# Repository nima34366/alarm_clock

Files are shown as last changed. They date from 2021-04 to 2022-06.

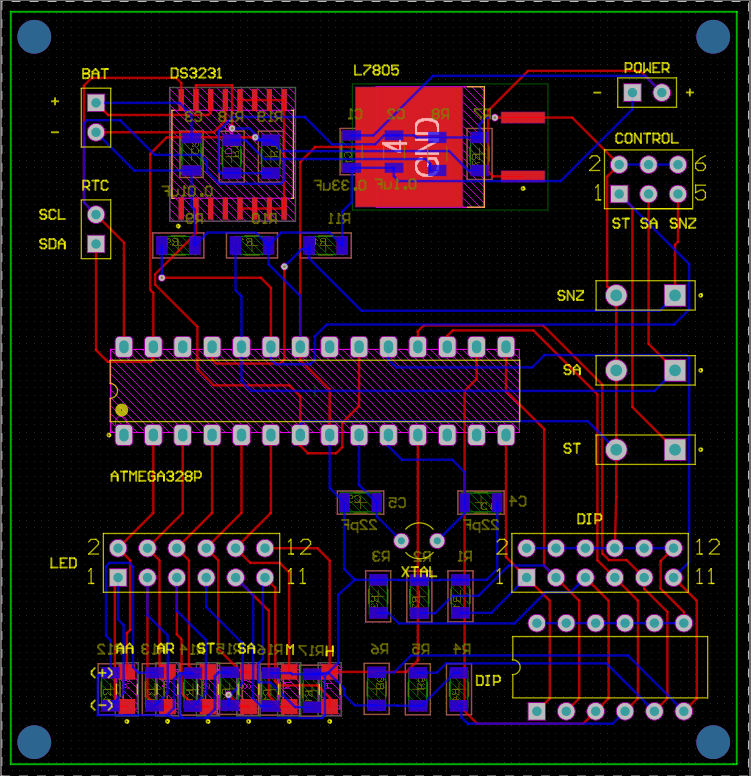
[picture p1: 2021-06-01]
microproducts/alarm_timing/pcb_design/PCB Layout.png

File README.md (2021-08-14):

# alarm_clock
This repository was created by Group 28 [Batch 19] for the Lab project (Alarm Clock) done in Semester 2 in University of Moratuwa.

It contains,
- The code required to function the Alarm clock along with code that is required to interface it with the ATMEGA644P, 16x2 LCD Screen, 4x3 Matrix Keypad and Buzzer.
- Pdfs of the schematics and layout used to create the PCB and the final renderings of Enclosure cerated using Solidworks.
- The latex files used to create the Final Report.

Link to the Google Drive that contains Altium and Solidworks files used to create the PCB and Enclosure: https://drive.google.com/drive/folders/1GlEg0UCcHJv6p5PrgpzKblIw5QNwTWeP?usp=sharing

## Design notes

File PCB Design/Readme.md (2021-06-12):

# Documentation of the PCB Design for the final Alarm Clock

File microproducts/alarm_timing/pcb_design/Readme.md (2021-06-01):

# PCB Design
This folder contains the documentation of the PCB design.\
The complete Altium project folder can be viewed from the following link.\
https://drive.google.com/drive/folders/1xslyNMAareKGrAWDZLLcO-WtdoEgDhnP?usp=sharing \

The PCB has the DS3231 RTC IC integrated onto it and is controlled by ATmega328P microcontroller.\
LEDs and switches have been used as indicators and controllers. These LEDs and switches have been placed on the PCB board but separate sets of headers have been added to draw wires when they need to be installed on an enclosure.\
SMD LEDs, resistors and capacitors have been used to decrease the area size of the PCB.\
The manufactured and assembled PCB's photographs are included in the drive link along with a demo.\

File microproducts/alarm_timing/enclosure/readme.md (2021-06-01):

# Enclosure Design
This Folder contains the design files of the Enclosure.\
All the Solidworks files can be accessed through the following link.\
https://drive.google.com/drive/folders/11zQsuTPlsv7nsFcpykirxAldbuCoP8ur?usp=sharing

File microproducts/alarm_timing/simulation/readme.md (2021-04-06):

# Files of Proteus simulation

The stage 1 implementation on the breadboard is demonstrated in the following video.
https://drive.google.com/file/d/18iBrARlaOofpYiVowA4YhBBXxcqHcPaR/view?usp=sharing

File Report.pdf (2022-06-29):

# Alarm Clock EN1093 - Semester 2 Project

Wickramasinghe N.L. 190688X∗

, Widanagamage T.R. 190691B†
,
Widanapathiranage D.N. 190692E‡

, Wijegunawardana C.H.W. 190696U§ Department of Electronic and Telecommunication Engineering University of Moratuwa, Sri Lanka Email: ∗wickramasinghenl.19, †widanagamagetr.19, ‡widanapathiranagedn.19, §wijegunawardanachw.19@uom.lk

Abstract—Our objective was to design and implement an alarm
clock that includes set time, date, and alarms throughout the day with the features of delete, change, and selecting an alarm tone. Initially, the complete code was implemented using Arduino C++. We transferred it into AVR C++ at the latter part of the project. For testing purposes, Proteus software was used. In parallel to the code, schematics and PCB layout were developed while having an idea of the conceptual design. The enclosure design was developed using Solidworks, including all the features needed to set the alarm for the user. Further, the physical product was developed to get final results, correcting all the impairments beforehand using proteus simulation. Throughout this project, we gained programming skills, improved logical thinking, PCB design skills, enclosure designing skills, and improved teamwork skills.
I. INTRODUCTION
In this paper, we have discussed the development of a digital alarm clock. Our objective was to create an alarm clock with the functions of,
- Set current date and time
- Set an alarm with the features of change, delete, and selecting a tone
- Factory reset
We navigated through various challenges to identify and experience the whole process of developing a product from scratch to the final complete product.
The significant parts of the alarm clock are keypad input, LCD, alarm timing, and audio output. Complete firmware for the parts was developed separately and combined to develop the final firmware using AVR C++. The ATMEGA644P microcontroller was used to develop this product.
In this paper, we have included the methods of the development of,
- Firmware
– Algorithms for each of the subsystems key input, menu display, alarm timing, and audio output
– Final Algorithm
- PCB Design
– Components used
– Schematic Diagrams
– PCB layout
- Enclosure Design
The objective of our project was to create a digital alarm clock that had a smooth user interface while having all the functions required in an alarm clock. We also worked on creating an accurate PCB that required very little space and, finally, creating a sleek and modern enclosure design for the product.

II. METHOD

A. Firmware Development

The task was to come up with an algorithm to implement an alarm clock with the following functions. The user should be able to add multiple alarms and add favorable tones to each of those alarms.
1) Set current time
2) List the existing alarms
3) Change or delete an alarm
4) Set a new alarm
5) Select an alarm tone
6) Factory reset
The system was planned to be implemented on AT-Mega328p microcontroller which has 32kB memory. But the memory was found to be insufficient for the developed algorithm mainly due the memory taken up to store multiple tones for alarms and other arrays. Therefore, the microcontroller was upgraded to an ATMega644p which has 64kB of memory and has a DIP package. The firmware was developed for this microcontroller using Microchip Studio. The algorithms were tested in several initial stages on Proteus simulation software. During the prototype development, the code was uploaded to the microcontroller using USBasp open-source programmer via the AVRDude interface.
A keypad was used to take number inputs from the user and an LCD was used to display the user interface of the clock. A sound system comprised of a buzzer was used to generate sounds for the alarms. The alarm clock keeps track of time and date using the RTC IC DS3231 which communicates with the microcontroller through the I2C interface.
The firmware development was initially divided into 4 main sub-systems in which each member developed a library of functions to perform a unique set of tasks. Based on these firmware libraries, four independent micro-products were developed to demonstrate each of the set of functions that will later be combined to create the final product. The sub-systems and each of their functions are in Table I.

Sub-system | Functions
Key Input | Read number input from a 4x3 keypad Detect button pressings
Menu Display | Display messages generated by the microcontroller on the 16x2 LCD
Alarm Timing | Set time and date Set/Delete alarms Detect alarms
Audio Output | Select multiple tones Drive a buzzer to ring a tone
| Table I
SUB-SYSTEMS AND FUNCTIONS.

The microproducts were implemented in two stages. The team members developed the algorithms to implement each function and tested the algorithm using codes written in Arduino C++. These codes were tested on Arduino Uno boards using Proteus software. After satisfactory results the firmware was developed in AVR C++ for the ATMega microcontroller. All the tasks were written modularized into functions and all the inter-related functions were combined into header files(.h and .cpp files). The microproduct implementation was done using these header files.
Algorithms
1) Key Input: This sub-system provides two main functions from Table I. The keypad read function will wait for a keyinput from the user when the function is called. Once the user presses a key in the keypad, the function returns the pressed key as an integer. Figure 1 shows the algorithm of that function.

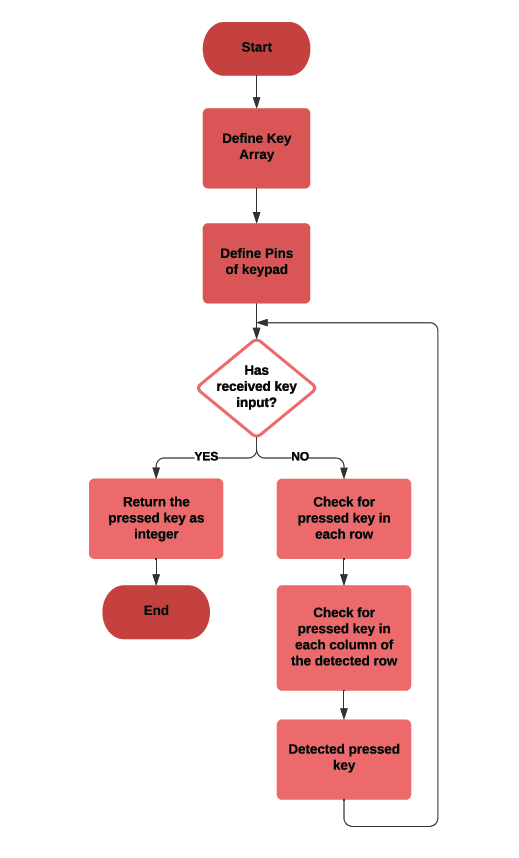
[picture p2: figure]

Figure 1. Keypad Read Algorithm

The button press function checks if a switch has been pressed and return True if yes, False if not.The algorithm is illustrated in Figure 2.

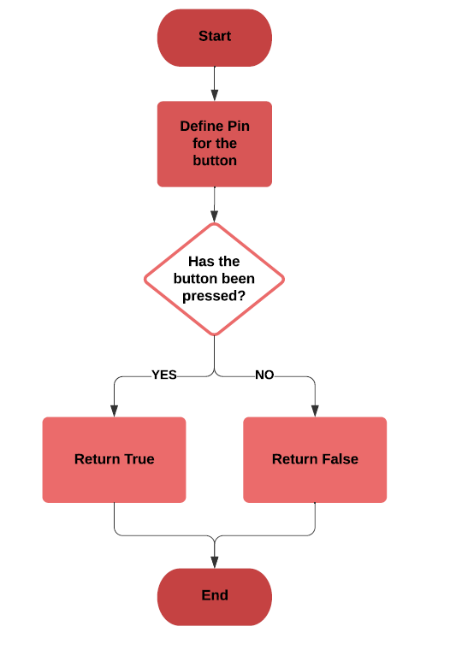
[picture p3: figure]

Figure 2. Button Press Algorithm

2) Menu Display: Two types of functions were written for controlling and displaying messages on the LCD.
- Control Functions
- Display Functions
The Table 2 and Table 3 shows the control functions and display functions respectively.
Function Name | Task Performed
LCD_Command(cmd) | Sending unique commands to setup the LCD
LCD_Char(char) | Sending unique characters to setup the LCD
LCD_Init() | Initial setting up of the LCD
LCD_String(string) | Sending a string to LCD
LCD_String_xy(row,col,string) | Sending a string to LCD with (x,y) position
LCD_Clear() | Clear LCD
Table II
DISPLAY FUNCTIONS OF LCD
3) Alarm Timing: The firmware for this sub-system was written based on objected oriented programming. Three classes were created with their own variables and methods. The classes are
- Time
- DS3231
- Alarm
a) Class Time: This class consists of the following set of variables that define the Time/Date. A single constructor method exists to create an instance of class Time.
- Hour
- Minute
- Second
- Year
- Month
- Day

Function | Snapshot

Home

Menu

Invalid Input

Set Time Menu

Alarm List

Alarm Menu

Select Tone

Setting Digits

Confirm Time/Date/Alarm

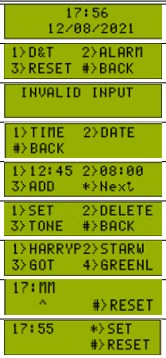
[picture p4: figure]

Table III
DISPLAY FUNCTIONS OF LCD
b) Class DS3231: This sub-system interacts with the RTC DS3231 IC to maintain the timekeeping. As aforementioned, the microcontroller communicates with this IC through I2C communication. This class contains the variables and methods required for that purpose and the functions for setting/reading time and date to/from the registers of the RTC IC. The necessary registers of the IC were referred from it’s datasheet. [1] The following necessary set of functions that interface the I2C communication[2] and encoding/decoding functions were written. They are provided in Table 4.
Function Name | Task Performed
begin | Initialize pins and bit rate and enable TWI
burst_read | Send address to start reading and read from that address
write_register | Send address to write value and write to that address
decode | Convert hex representation to integer value
encode | Convert integer value to hex representation
Table IV
I2C FUNCTIONS

Then these functions in Table 5 were used to write the following functions to be used in the timekeeping.

Function Name | Task Performed
set_Time | Write time to necessary registers in the IC
set_Date | Write date to necessary registers in the IC
get_Time | Read Time/date from registers and return the time as an object of Time
get_TimeStr | Return a string of time
get_DateStr | Return a string of date
Table V
TIMEKEEPING FUNCTIONS

Using the above three classes, five central functions were written to perform the following tasks.

Function Name | Task Performed
Timing_set_time | Read input from keypad and set time
Timing_set_date | Read input from keypad and set date
Timing_set_alarm | Read input from keypad and set an alarm
Timing_delete_alarms | Delete all alarms
Reset_time | Factory reset
Table VI
ALARM TIMING FUNCTIONS

The algorithm that was being used to set time/date/alarm is given in Figure 3.

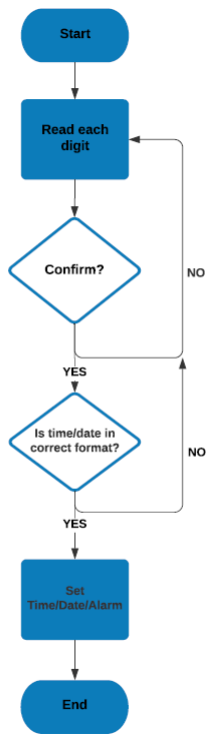
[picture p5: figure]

Figure 3. Set Time/Date/Alarm Algorithm

4) Audio Output: All the notes with the durations were taken from a github repo [3].They were modified to create two seperate header files. One header file “notes.h” defined the frequencies of each note of music used in the tones. The second header file “tones.h” defined two arrays with the notes and their respective durations for each of four tones as follows.
- Harry Potter
- Star Wars
- Game of Thrones
- Green de Leaves
A class Tone was created with the following variables and two functions.
- Array of note

- Array of durations
- Length
- Rate
The following functions in Table 7 were implemented to perform the respective tasks.
Function Name | Task Performed
Play_note | Play the note for the respective duration on the buzzer
Audio_play | Play the tone until the user stops the alarm
Table VII
AUDIO OUTPUT FUNCTIONS

The following Figure 4 and Figure 5 show the algorithms for play_note and audio_play functions.

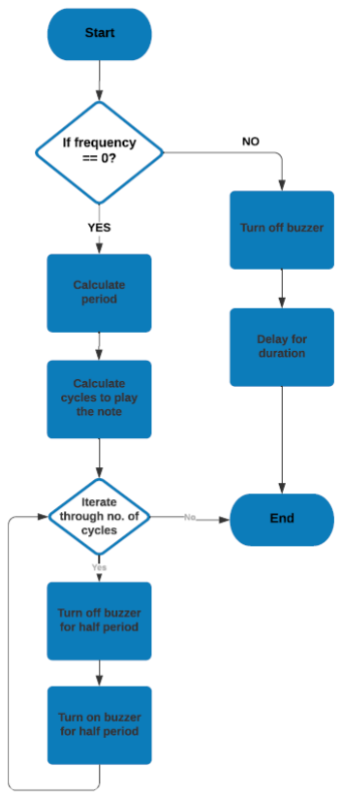
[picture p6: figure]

Figure 4. Play Note Algorithm

Final Product
The algorithm of the final product implemented a user interface of a menu system for the alarm clock according to the following algorithm in Figure 6. It makes use of functions of the above explained header files.
The checks for alarm times were implemented using software interrupts. The reason for using interrupts was to detect alarms even when the user is in the middle of the menu. The Timer Overflow Interrupt of 16-bit Timer/Counter 1 of ATMega644p was used in this case. The interrupt service routine (ISR) was written to iterate through each alarm in the

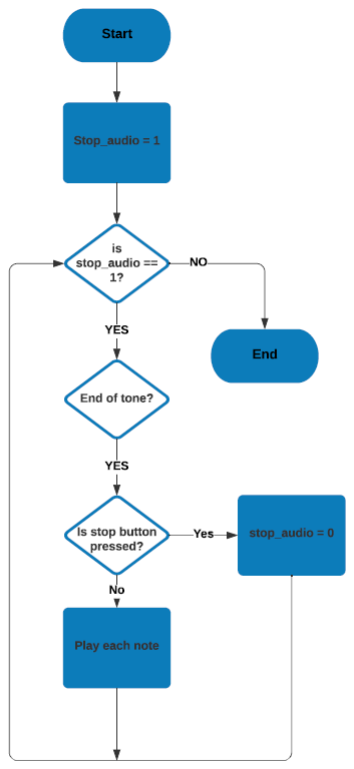
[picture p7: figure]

Figure 5. Audio Play Algorithm

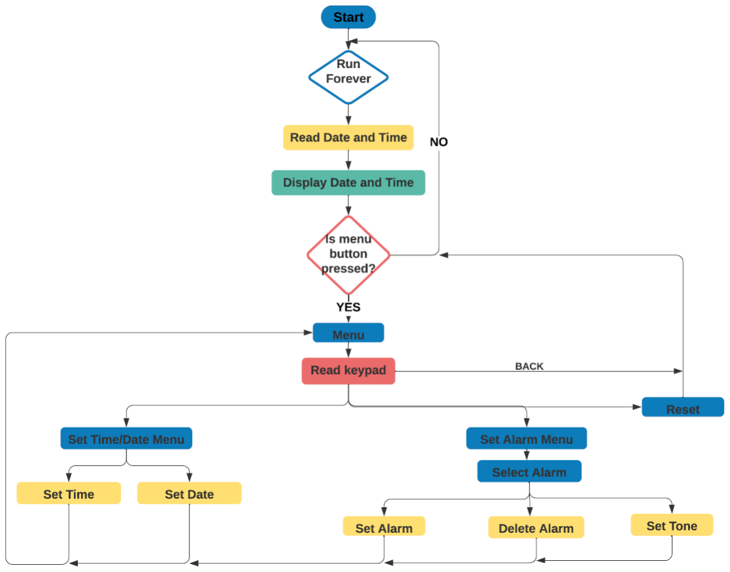
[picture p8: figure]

Figure 6. Main Algorithm

alarm list and check whether the time is equal to any of the active alarms. If found, its ring function will be called. Between the menu, an error message was programmed to be displayed whenever the user entered an invalid input. The AVR C++ codes of the firmware of the alarm clock can be found at the GitHub link in the appendix.

B. PCB Design
1) List of components used:
a) Microcontroller: According to the Atmega644p microcontroller datasheet, 0.1 uF bypass capacitor was provided to connect VCC and GND. [4]
- Atmega644P microcontroller
- 0.1 uF capacitor
- Reset switch
- 10k resistor
b) Power regulator: LM7805 has been selected as the regulator and according to the datasheet the two capacitor values were chosen. [5]
- 2 pin header for the power supply.
- LM7805
- 0.33 uF capacitor
- 0.1 uF capacitor
c) Programmer:
- 10 pin header for the USBASP
d) Buttons:
- 2 pin header *2 for the menu button and stop button.
- 10k resistor
e) Keypad:
- 7 pin connector for the keypad
- 10k resistor*4
f) LCD display:
- 12 pin connector for the lcd display
- 1k resistor
g) RTC clock: According to the DS3231 datasheet values of the resistors have been decided. [1]
- DS3231 IC
- 10k resistors*2
- 2 pin header for the coin cell battery
h) Buzzer:
- 1N4001 diode
- BC547 transistor
- 220 resistor
- 2 pin header for the buzzer
i) Oscillator:
- 16 MHz crystal oscillator
- 22 µF capacitor*2
Reasoning for use of particular components Microcontroller: Atmega644P microcontroller was chosen for the project due to several reasons. First, the program was implemented using 328P microcontroller and the memory of that was not enough. Atmega328P has 32 Kbyte flash memory, 1 Kbyte EEPROM and 2 Kbyte RAM. Then the microcontroller was upgraded to Atmega644P [Figure 7, Figure 8] because it has 64 Kbyte flash memory, 2 Kbyte EEPROM, 4 Kbyte RAM and 40 pins. [4]
Keypad: 4*3 keypad was chosen instead of 4*4 keypad because only ‘*’ button and ’]’ button were taken other than the number buttons for the control of going back and set functions.

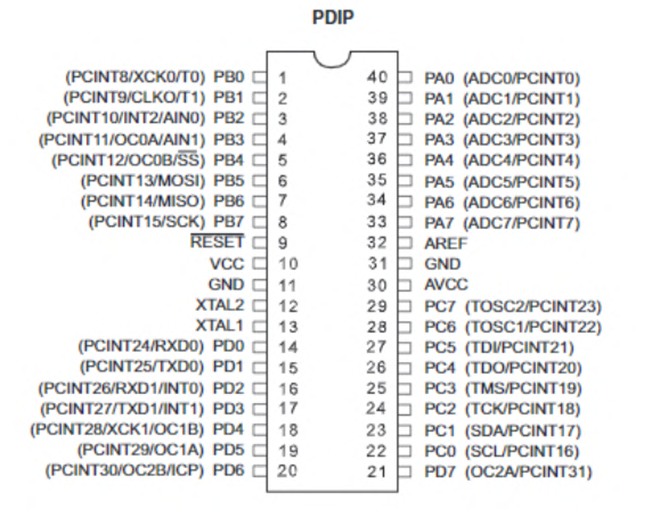
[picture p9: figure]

Figure 7. Pinout644P

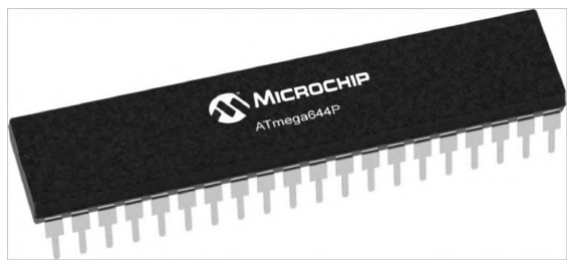
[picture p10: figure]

Figure 8. Atmega644P

Switches: The purpose was to minimize the number of switches in the enclosure for the convenience of the user. Even through a button of the keypad can be taken for the menu button, a separate switch is provided because the user will be used menu button several times and if there’s a separate switch user can recognize it easily as menu button other than providing a keypad number as the menu button. There is another switch for stop alarm because if it is given as a keypad button, user gets difficult to off while awake in sleep. Therefore, a separate button is provided for the stop alarm, then user can easily switch off.
Real Time Clock(RTC) IC: After comparing DS1307 and DS3231, DS3231 module was selected. DS3231 IC is more accurate than DS1307 IC but it is existing only as a SMD component. DS3231 has been chosen because it’s not an issue for soldering. [1]
Buzzer circuit: A transistor has been used for the amplifying purpose and a diode has been used to make the protection for the buzzer.
Batteries: There are two batteries, 1.5V, 4AAA batteries are used as main voltage supply and a silver coin cell battery is used as a backup battery for the RTC module. Even though there are two batteries, the user doesn’t always have to replace the coin cell battery, because the coin cell battery provides current to the RTC module only if there isn’t a main voltage supply. The required current for the DS3231 IC module is given in the datasheet as 200 uA. The capacity of a silver coin cell battery is 200 mAh. If coin cell battery provides 20 hours of current per month, the user can use one coin cell battery for about 4 years without replacing it. The required voltage for the circuits is 5V. Then it should supply 5v or more than that. The batteries available in the market are AA and AAA batteries. Therefore four 1.5v batteries must be provided. The size of the AA batteries is quite larger than AAA batteries therefore the enclosure battery holder has to be enlarged. As a result, 4 AAA batteries were selected.
2) PCB layout: The Schematic diagram and the PCB Layout made for the design of PCB can be found in Figure 19 and Figure 20 respectively.
Considerations in PCB design
- The board size, neatness and the shortest routing path were generally considered.
- The placement of bypass capacitor(C3) near to the micro controller according to the data sheet.
- Minimized routing traces through the oscillator and placed near to the micro controller.
- Capacitors of the oscillator, placed near to it (C4, C5).
- The same value of resistors placed in line for the convenience of soldering purpose.
- All header connectors were placed close to edges of the board because of the convenience of connecting wires.
- Capacitors of the regulator, placed near to it. (C1, C2) The dimensions of the final PCB were 61.6 mm x 45.3 mm. The top and bottom of the 2D and 3D views can be found in Figures 21, 22 and Figures 23, 24 respectively.
C. Enclosure design
Designing the enclosure is one of most important parts in the process of product development. A product enclosure should have the characteristics of
- Strength – To withstand the stresses during normal use
- Functionality – Have the necessary components for proper functionality of the product
- Attractive – A sleek, aesthetic, and modern design to attract potential buyers
- Easy to handle – The product should be able to be operated by anyone without prior experience about the particular product
The goal of our team was to create a suitable enclosure for the housing of the electronics of our digital alarm clock. Our aim was to create an enclosure that would have the necessary strength for day to day use. It should also have the requirements to be easily opened for repairs and maintenance while having a very unique and aesthetic design.
Our enclosure had to be able to house the following components within the enclosure.[Figure 9]
- 2 x Momentary switch
- 1 x Printed circuit board along with the electronics
- 1 x Coin cell battery holder
- 1 x 4xAAA Battery holder
- 1 x Buzzer
- 1 x 4x3 Matrix keypad
- 1 x LCD screen display
- Necessary Wires
(a) PCB | (b) Keypad
(c) 4xAAA Battery Pack | (d) Momentary Switch
(e) Coin cell battery holder | (f) Buzzer
(g) LCD

Figure 9. Components to be placed within the Enclosure

Figure 10 shows the initial sketches we had planned for the enclosure design of the digital alarm clock.

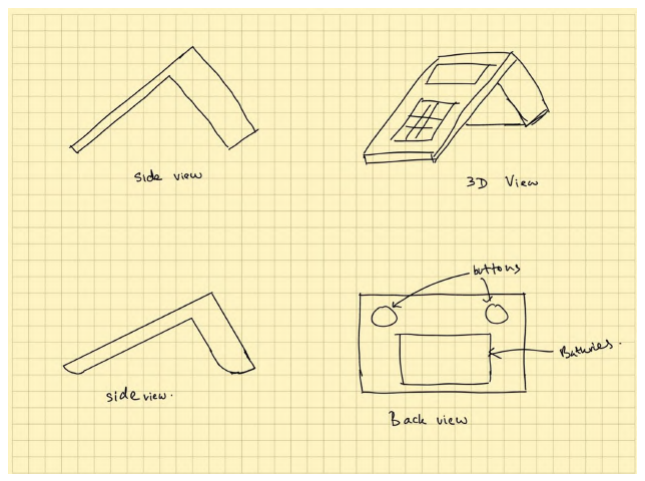
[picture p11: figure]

Figure 10. Initial sketches

Our Final enclosure is split into 3 separate parts.

- Bottom part
- Top part
- Battery cover

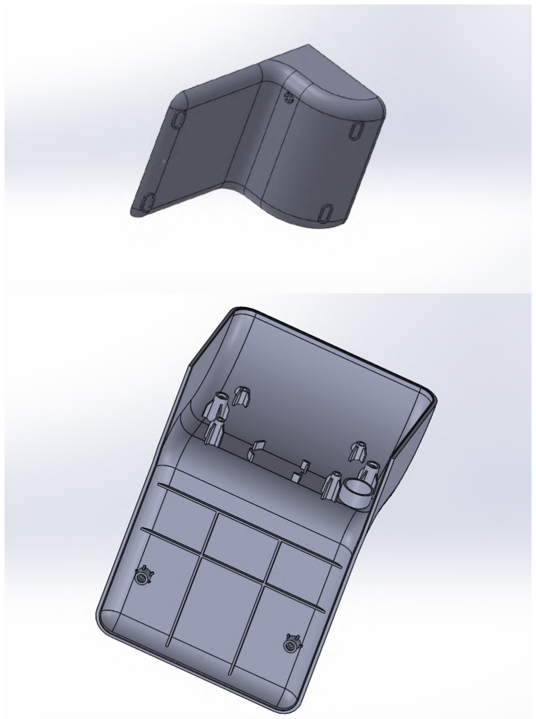
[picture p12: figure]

Figure 11. Bottom part

1) Bottom part [Figure 11]: The bottom part gets connected to the top part using four mounting bosses. Also, lips and grooves are etched onto the edges where the two parts meet. It also contains ribs for additional support and high strength. It also helps to maintain shape under high-stress conditions. The bottom part houses the coin cell battery, PCB, and the buzzer. We created a separate slot to accommodate the coin cell battery. The PCB is mounted on 4 mounting bosses. A circular slot is separately carved to accommodate the buzzer. A vent is created on the bottom side to pass the sound of the buzzer outside. 4 straight slots are etched onto the bottom surface, where rubber pads will be attached later on. The rubber pads on the bottom will help stabilize the product and help stop slipping.
2) Top part [Figure 12]: The top part too includes the required mounting bosses to connect to the bottom part along with the lips and grooves. It houses the 4x3 matrix keypad, LCD, 4xAAA battery holder, and the two momentary switches. Separate holes are cut out for the momentary switches to be attached. The holes have a carving above them so that the user can easily identify the function of the switch. A 1mm depth slot is carved out in the front face to accommodate the 4x3 matrix keypad. A small slot is cut at the bottom to get the wires inside the enclosure. A large window is cut at the top part of the front face for the LCD screen. Also a large slot is created at the back to accommodate the 4XAAA battery

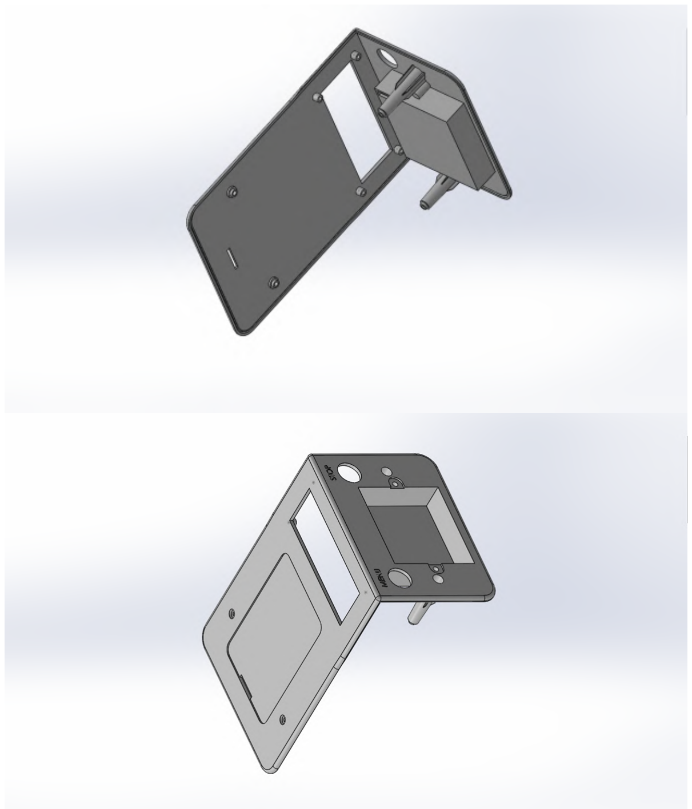
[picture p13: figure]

Figure 12. Top part

holder. It also contains the holes required to attach the cover of the battery compartment.

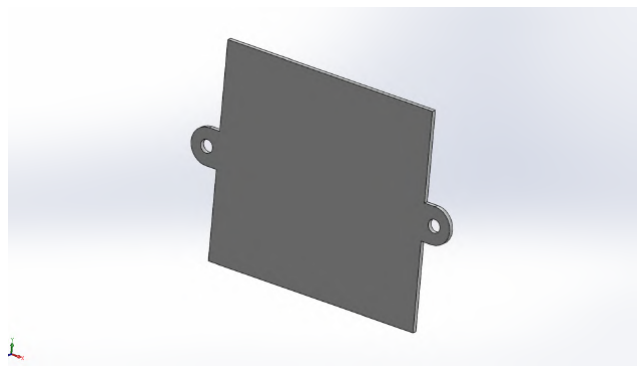
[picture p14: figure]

Figure 13. Battery cover

3) Battery cover [Figure 13]: A separate cover is created in order to cover the 4xAAA battery holder. The cover is fastened on to the top part using two screws.
The bottom part was colored with blue and the top with white for the final product. We used SolidWorks software for the creation of the 3D models. [Figure 14]

III. RESULTS

The alarm clock design was tested using the schematic in [Figure 15] using Proteus simulation software. The design was tested for setting time and date, setting multiple alarms, deleting alarms, detecting the alarms, stopping the alarm and resetting functions. All four tones were tested successfully.

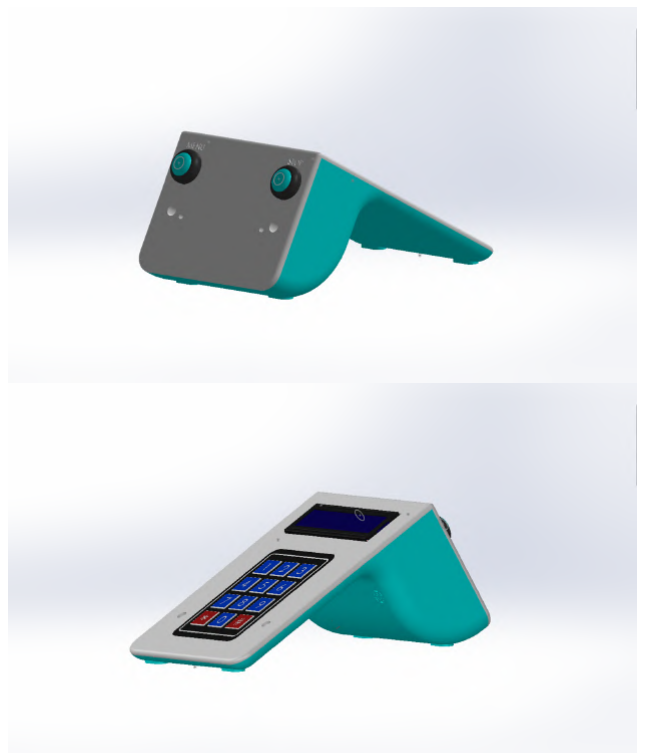
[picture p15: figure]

Figure 14. Final Enclosure

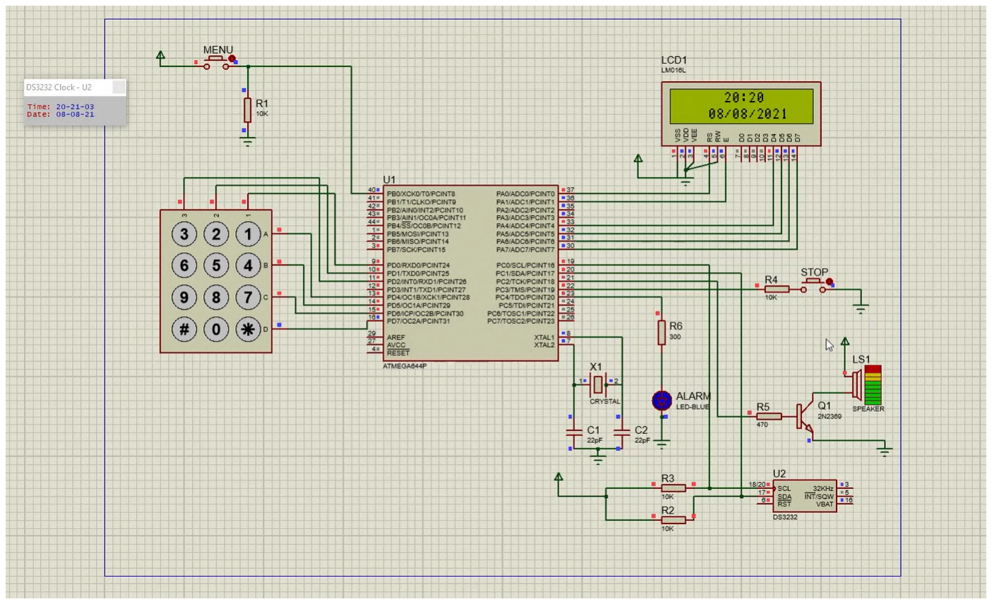
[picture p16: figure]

Figure 15. Proteus Simulation

A recording of the Proteus Simulation could be found by following the Google Drive link in the appendix. After the algorithm and the schematic were confirmed using Proteus, the circuit was implemented on breadboard to be evaluated on real-life aspects. The circuit performed as expected giving similar results as in Proteus simulation. [Figure 16] shows the breadboard testing.

Then the PCB was manufactured from JLCPCB from China and the components were purchased from Arrow Electronics. [Figure 17] [Figure 25] [Figure 26] The components were hand soldered to the PCB and tested using a prototype in [Figure 18]

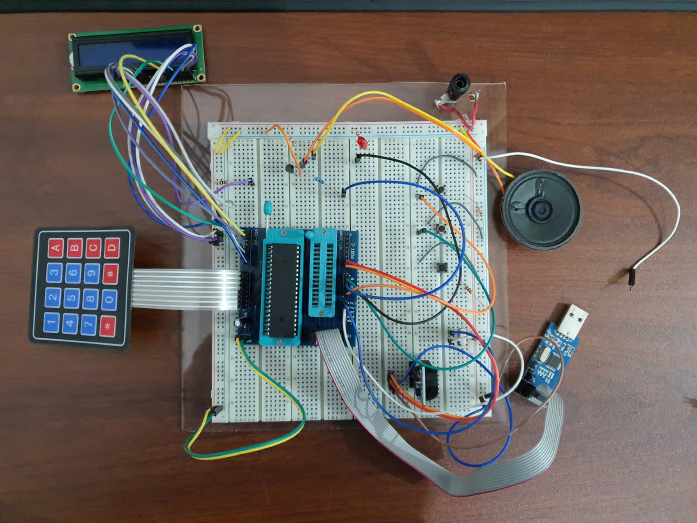
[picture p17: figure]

Figure 16. Breadboard Testing

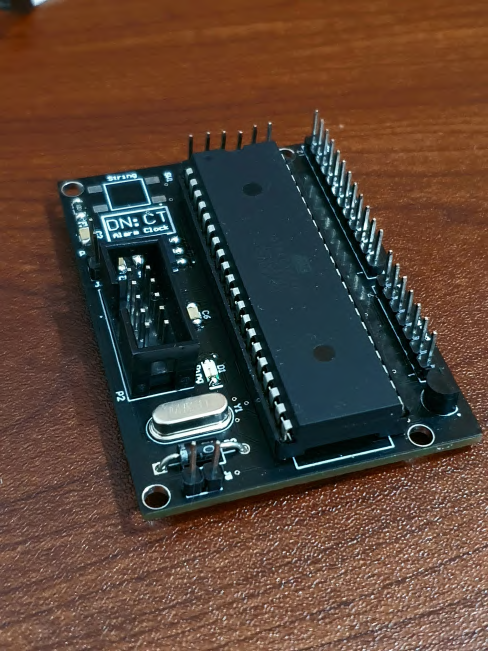
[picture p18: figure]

Figure 17. The Fabricated PCB

IV. DISCUSSION
There were several challenges we faced during the project of designing the alarm clock. During the development of the firmware, it was required to combine modularized code written by several people into a single project. To make it easier, a flowchart was drawn for the central algorithm and the functions were modified into a common code writing style. The codes were well documented to be understood by other collaborators. After making the circuit on the breadboard, the Port C of the micro-controller happened to be not working properly, supposedly due to the continuous I2C communication through the same port. The components on Port C were shifted to unoccupied pins in Port B. However, this error did not occur in the Proteus simulation which emphasized the

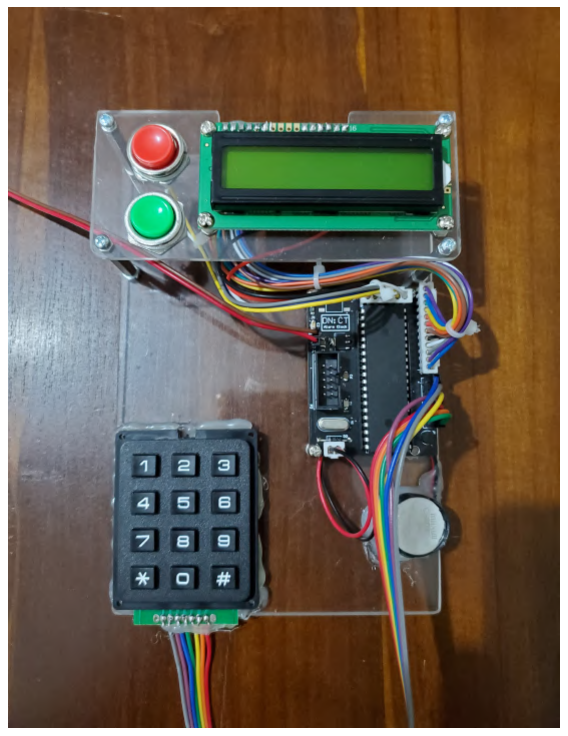
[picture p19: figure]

Figure 18. Prototype

importance of testing the circuit in physical conditions. Compacting components to get a smaller PCB was a challenge when designing our PCB. Specially, the upgraded micro-controller Atmega644P is considerably larger than the previous Atmega328P which in turn increased the form factor. The final dimensions of the PCB were 61.6 mm x 45.3 mm, which is satisfactory. The PCB was manufactured by JLCPCB. Therefore, it was required to adhere to the rules given by JLCPCB. The pads around the pins of the transistor in its footprint were too close to each other, violating clearance rules. To solve this, the size of the pins of the transistor were taken from it’s data sheet and the footprint was adjusted. When placing the components, the components which are taller in height like headers were placed only on one side of the PCB to avoid being required to keep space on both sides of the PCB when it is being mounted in the enclosure. Also, even though the coin cell battery can be inserted on the PCB itself, it was placed in the enclosure because the purpose was to make PCB smaller in size.
Software, such as SolidWorks, helped us to easily design unique and functional enclosures for our electronic products. Most of the 3D models for the components we used could be found online, which was very helpful when deciding the required dimensions for the enclosure. Although we planned to 3D print and assemble our final product, we were unable to do it due to not being able to gather the some of the components within the given time frame. But, the the error analysis method given by the SolidWorks software itself showed no errors with the final enclosure [Figure 14].
There are several improvements that could be made to the design of this alarm clock. The LCD could be connected to the micro-controller using an I2C multiplexer, which will reduce the number of pins required. Also, in our current design, 4 AAA batteries were used to supply 5V power to the electronic components. But this makes the alarm clock bulky and inconvenient for the user who will have to replace 4 batteries when they drain out. Instead, a boost converter could be integrated into the circuit to draw power from a single AAA battery. However, this was not implemented in the current stage of development, because it was not in our knowledge scope yet.
V. CONCLUSION
Design of the alarm clock for our semester 2 project for the module EN1093 helped us in gaining many technical skills as engineers. Developing firmware for an electronic product using ATMega micro-controllers, designing a schematic and a PCB layout for an electronic circuit using Altium, fabricating and soldering a PCB, designing a commercially viable enclosure for an electronic product using Solidworks and testing an electronic product for design verification were the most valuable skills we gained during the project. We adhered to the important stages of the product development life cycle and gained social skills of working as a team to achieve a common goal. Our design of the alarm clock performed all the functions of the project requirements, contained an easily comprehensible user interface using an LCD and a keypad, and possessed a stable and attractive enclosure.

ACKNOWLEDGMENT
We would like to express our sincere gratitude to our supervisors Mr. Kithmin Wickramasinghe, Mr. Abarajithan Gnaneswaran and Mr. Pasan Dissanayaka, for their enthusiasm, insightful comments, helpful information, and practical advice. All of them helped tremendously during the completion of this project. The project would not have been possible to complete without the support and guidance from the supervisors. We thank our parents for the financial support given to us in completing this project.

REFERENCES

[1] Maxim Integrated, “Ds3231 datasheet,” https://pdf1.alldatasheet.com/datasheet-pdf/view/336170/MAXIM/DS3231.html, (https://pdf1.alldatasheet.com/datasheet-pdf/view/336170/MAXIM/DS3231.html) accessed 15-07-2021.
[2] California State University, Long Beach, “Serial communications and i2c,” http://web.csulb.edu/~hill/ee346/Lectures/20%20C++%20ATmega%20I2C%20Serial%20Comm.pdf/, (http://web.csulb.edu/~hill/ee346/Lectures/20%20C++%20ATmega%20I2C%20Serial%20Comm.pdf/) accessed 15-07-2021.
[3] R. | Couto, | “arduino-songs,” | https://github.com/robsoncouto/
arduino-songs, (https://github.com/robsoncouto/arduino-songs) 2021.
[4] Microchip Studio, “Atmega644pa datasheet,” https://pdf1.alldatasheet.com/datasheet-pdf/view/313648/ATMEL/ATmega644PA.html, (https://pdf1.alldatasheet.com/datasheet-pdf/view/313648/ATMEL/ATmega644PA.html) accessed 15-07-2021.
[5] Texas Instruments, “Lm7805 datasheet,” https://pdf1.alldatasheet.com/datasheet-pdf/view/838007/TI1/LM7805.html, (https://pdf1.alldatasheet.com/datasheet-pdf/view/838007/TI1/LM7805.html) accessed 15-07-2021.

VI. APPENDIX
Link to GitHub Repository: https://github.com/nima34366/alarm_clock
The following Google Drive link contains the following documents related to the project: https://drive.google.com/drive/folders/1GlEg0UCcHJv6p5PrgpzKblIw5QNwTWeP?usp=sharing (https://drive.google.com/drive/folders/1GlEg0UCcHJv6p5PrgpzKblIw5QNwTWeP?usp=sharing)
- Microchip Project File
- Altium Project File
- Solidworks File
- Bill of Material
- Proteus Simulation
- Prototype Simulation

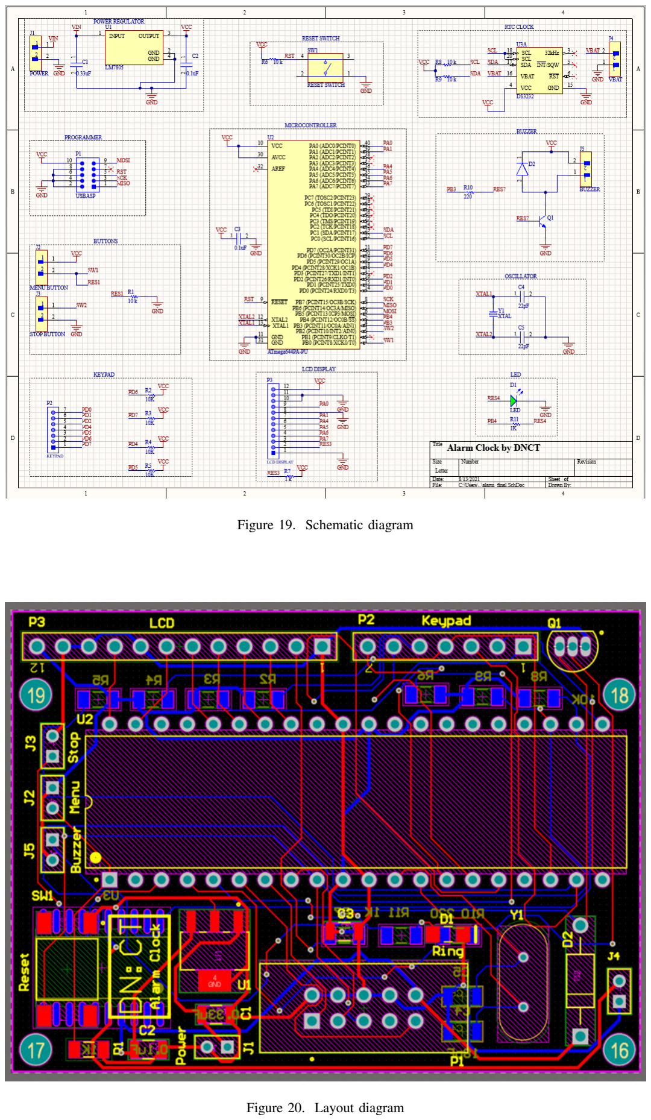
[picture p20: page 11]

Figure 19. Schematic diagram

Figure 20. Layout diagram

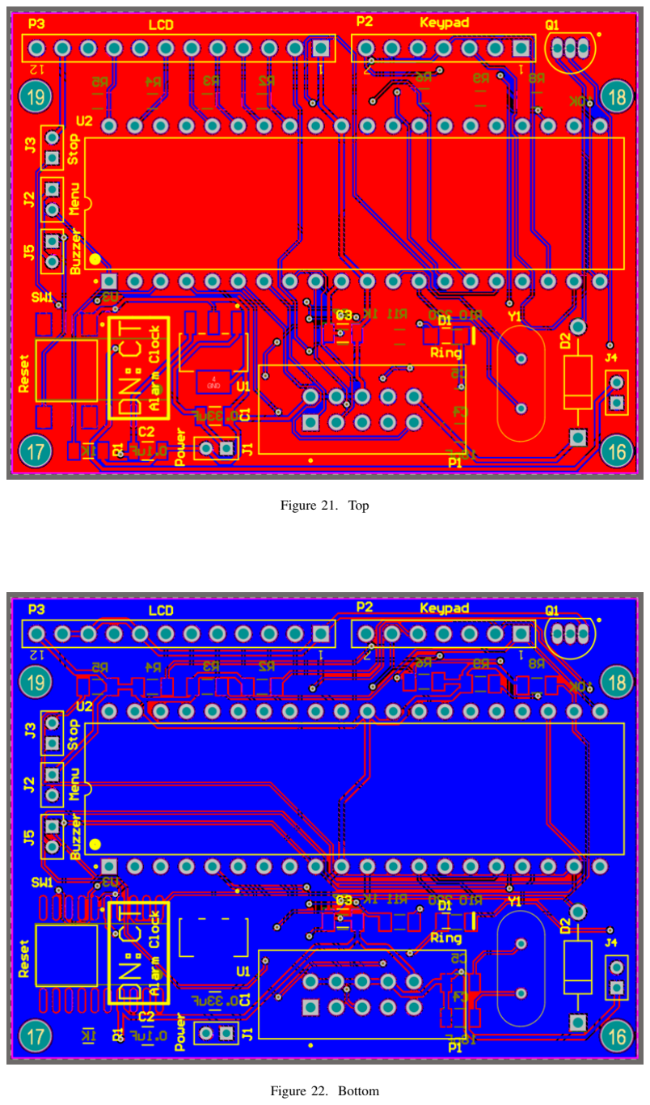
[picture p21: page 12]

Figure 21. Top

Figure 22. Bottom

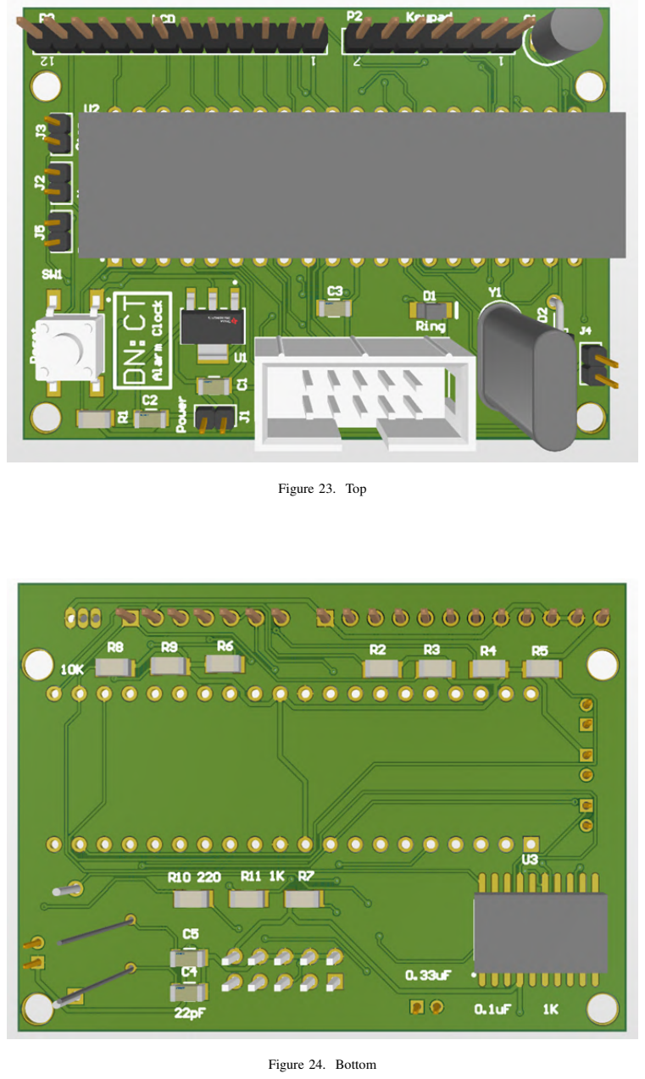
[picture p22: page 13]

Figure 23. Top

Figure 24. Bottom

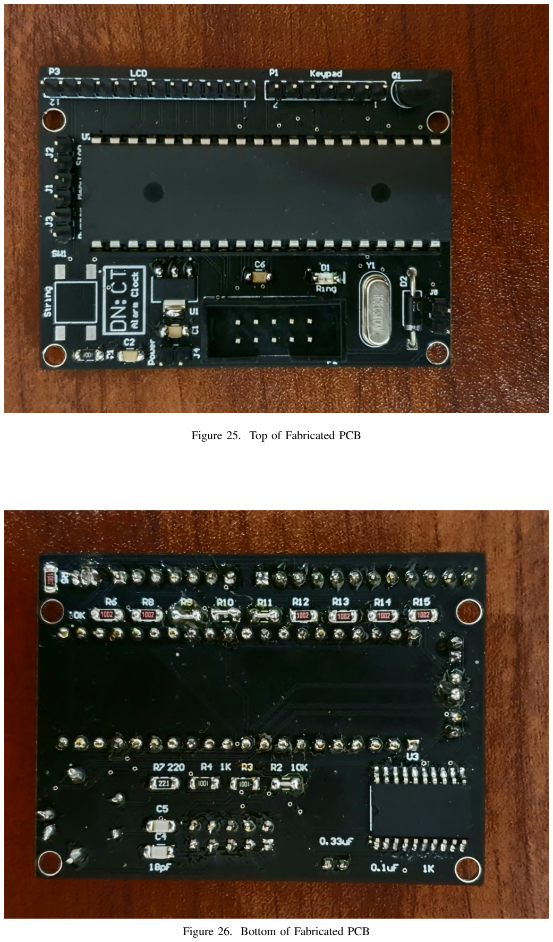
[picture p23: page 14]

Figure 25. Top of Fabricated PCB

Figure 26. Bottom of Fabricated PCB

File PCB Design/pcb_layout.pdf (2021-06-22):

PCB Layout

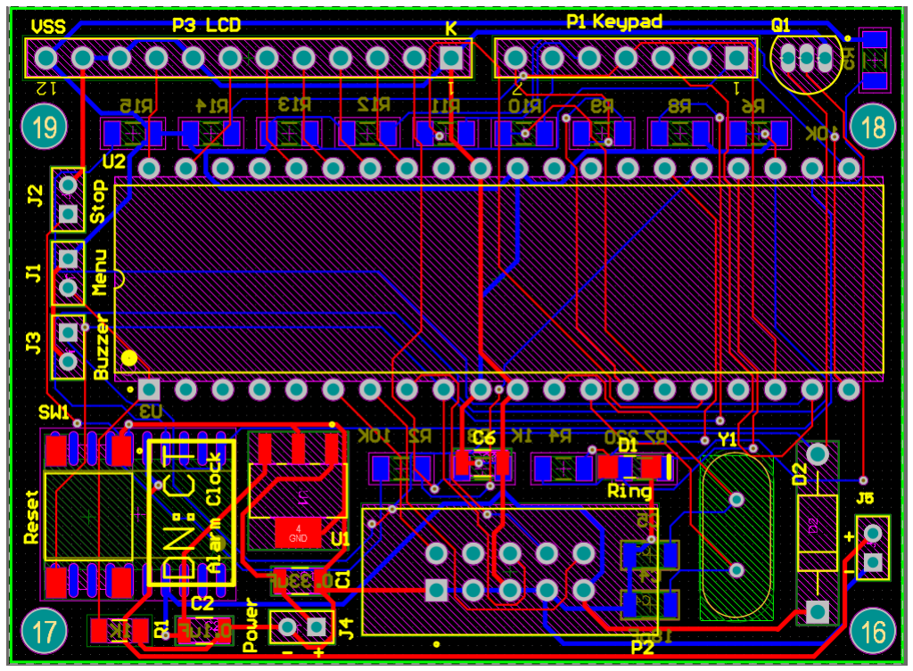
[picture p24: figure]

Routing

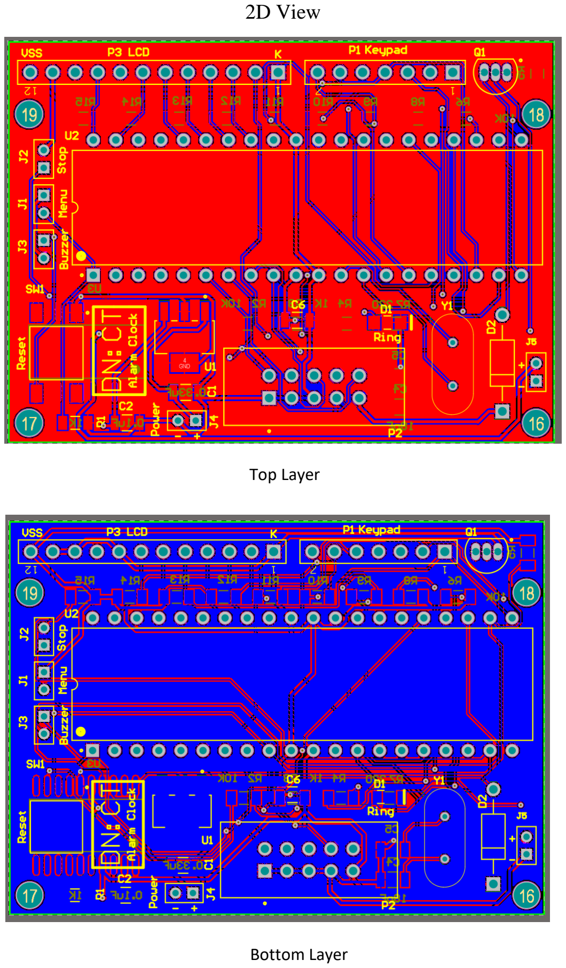
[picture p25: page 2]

2D View

Top Layer

Bottom Layer


3D View

Top View

Bottom View


Side View

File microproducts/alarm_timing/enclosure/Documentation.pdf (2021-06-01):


3D View

Top View


Front View

Left View


Cross View

Bottom View

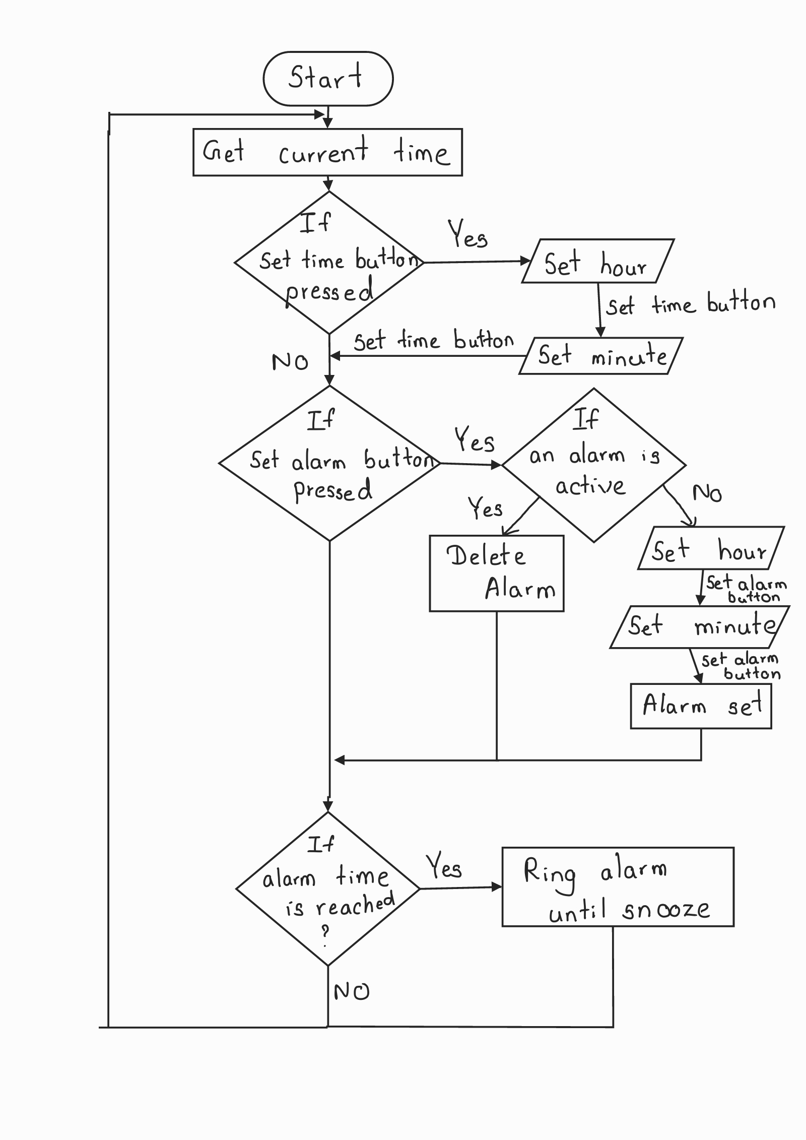
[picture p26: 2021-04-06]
microproducts/alarm_timing/simulation/Block Diagram of Alarm Timing.jpg

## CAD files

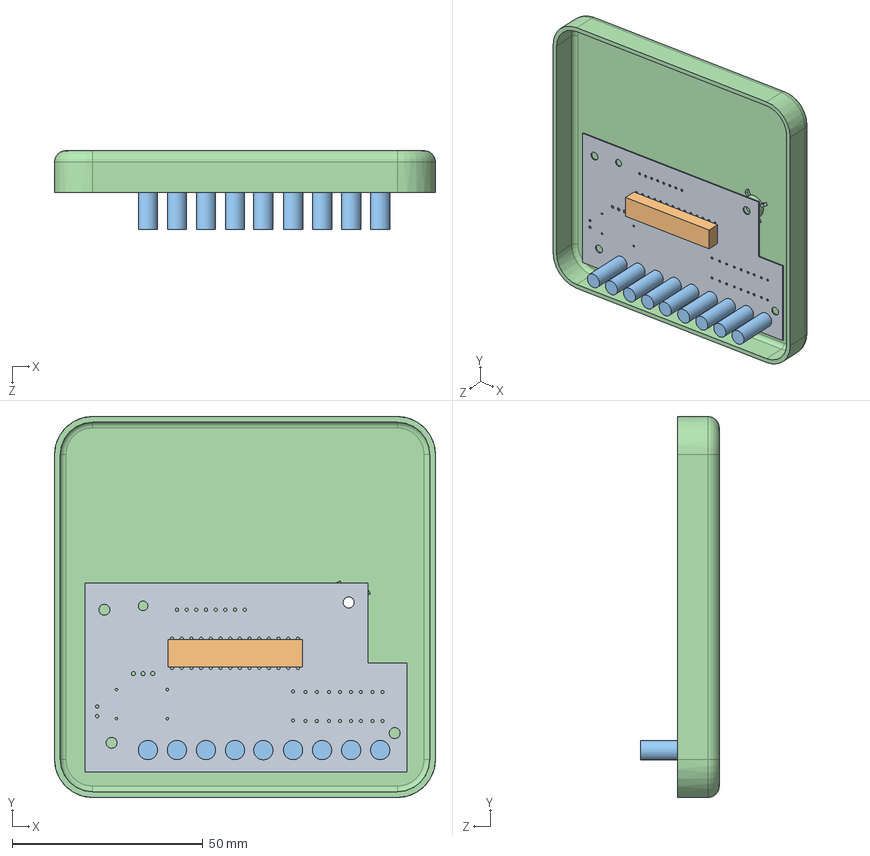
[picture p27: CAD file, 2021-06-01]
microproducts/key_input/enclosure/extra/Assem1.SLDASM
100.0 x 100.0 x 20.7 mm
Extruded.step
Cylinder.step x 9
Part4^Assem1

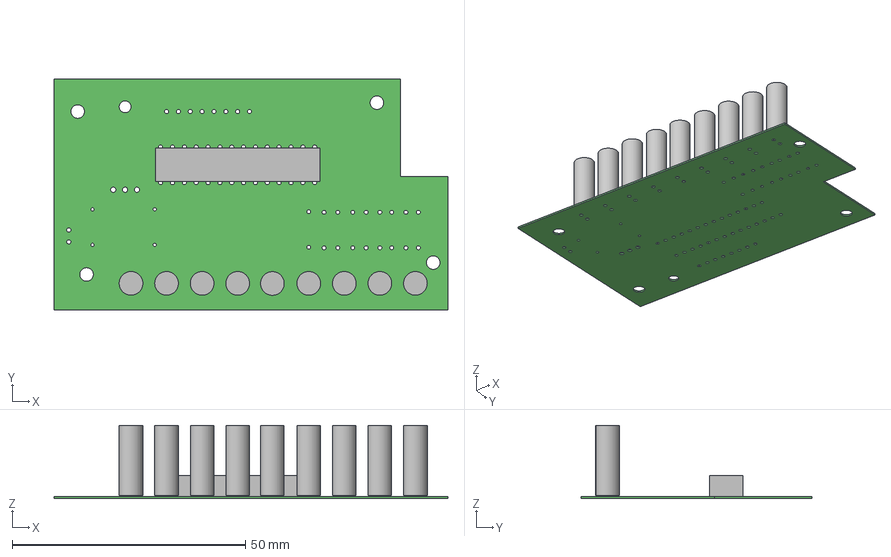
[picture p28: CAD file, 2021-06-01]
microproducts/key_input/enclosure/PCB2.step
84.5 x 49.5 x 15.7 mm
Extruded

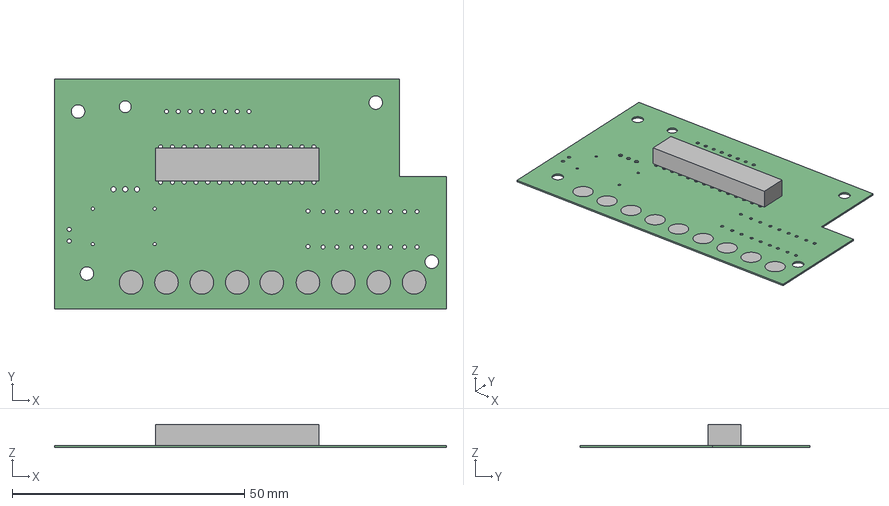
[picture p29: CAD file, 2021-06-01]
microproducts/key_input/PCB_Project/PCB1.step
84.5 x 49.5 x 4.99 mm
Extruded

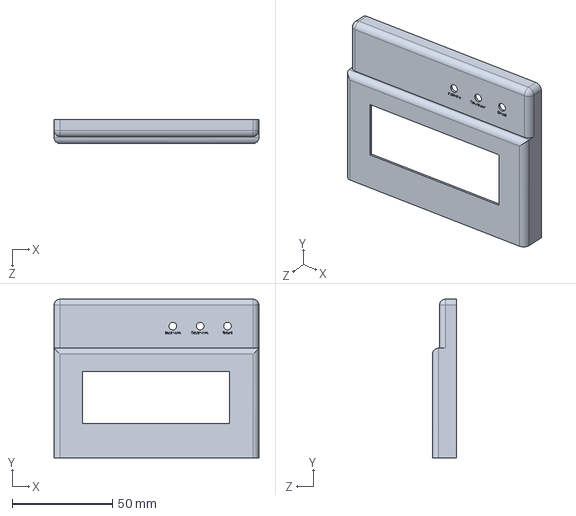
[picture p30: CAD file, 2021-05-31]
microproducts/menu_display/menu_display_avr/solidworks/Bot.SLDPRT
102.0 x 79.0 x 12.0 mm

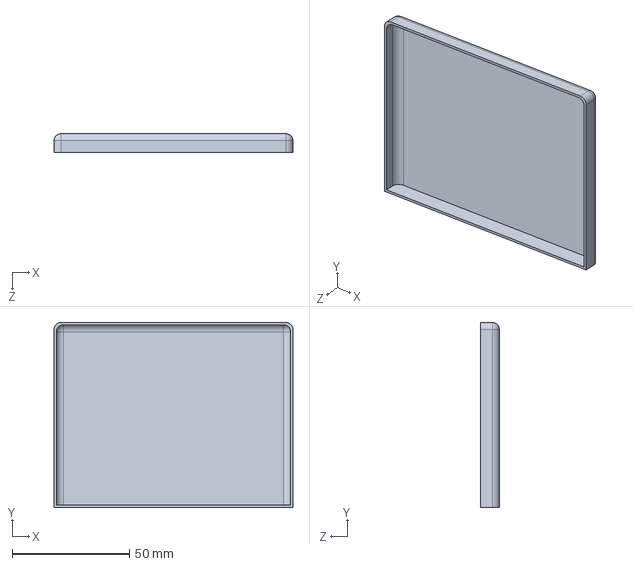
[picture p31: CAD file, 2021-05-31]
microproducts/menu_display/menu_display_avr/solidworks/Top.SLDPRT
102.0 x 79.0 x 8.00 mm

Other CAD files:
microproducts/menu_display/menu_display_avr/solidworks/Part35^alarm_clock.SLDPRT
microproducts/key_input/enclosure/PCB2.SLDASM

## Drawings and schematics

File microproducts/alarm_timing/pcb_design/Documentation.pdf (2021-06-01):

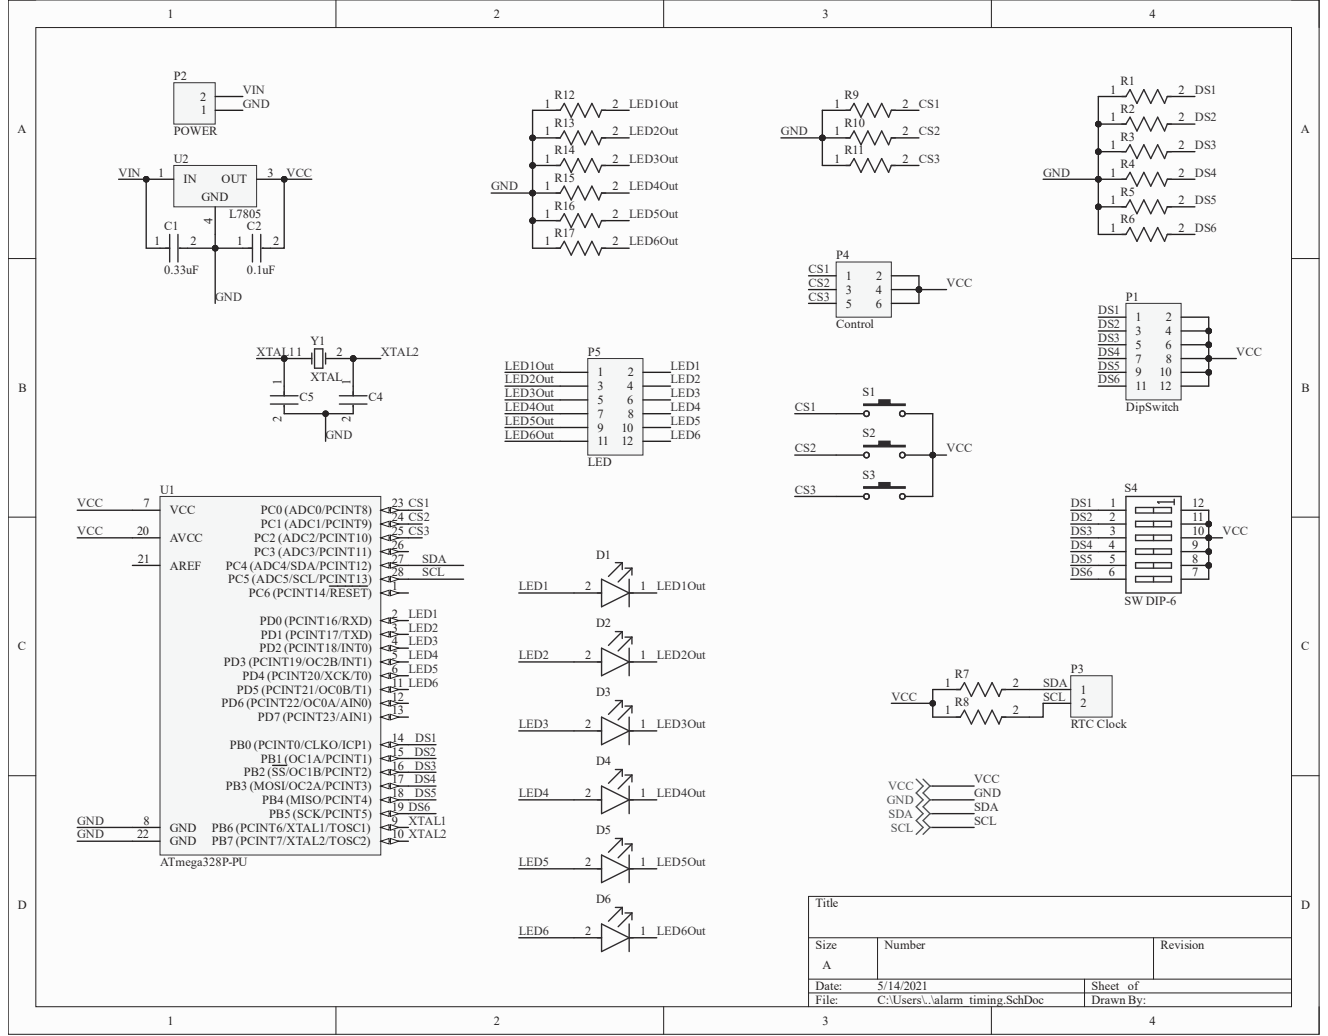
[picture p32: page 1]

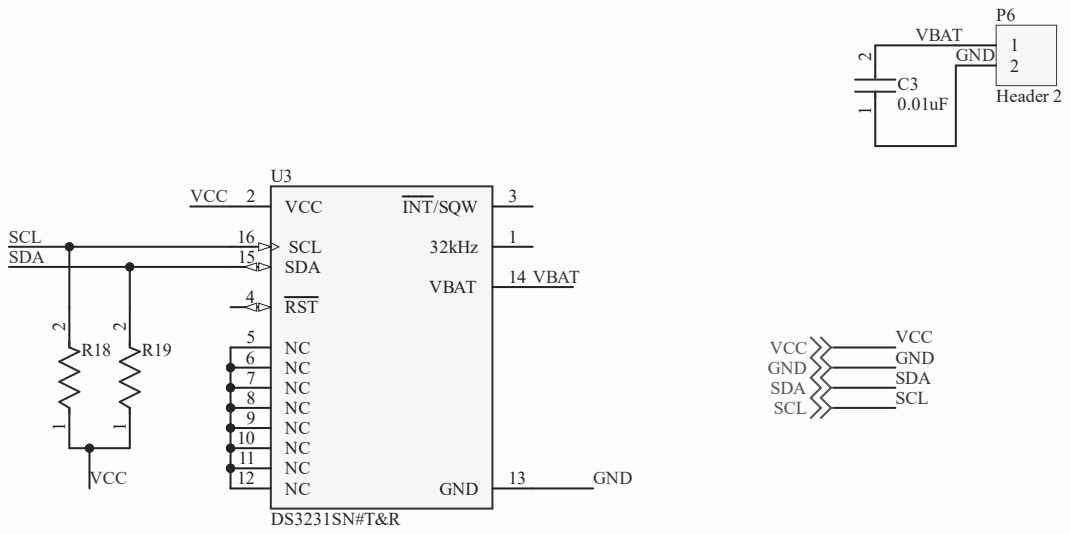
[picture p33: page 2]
Title; Size; Number; Revision; Date:; Sheet of; File:; C:\Users\..\DS3231.SchDoc; Drawn By:; VCC 2; 32kHz; INT/SQW; RST 4; SCL 16 SDA 15; VBAT; GND; VCC; Header 2; VBAT GND; VCC GND SDA SCL; SCL SDA

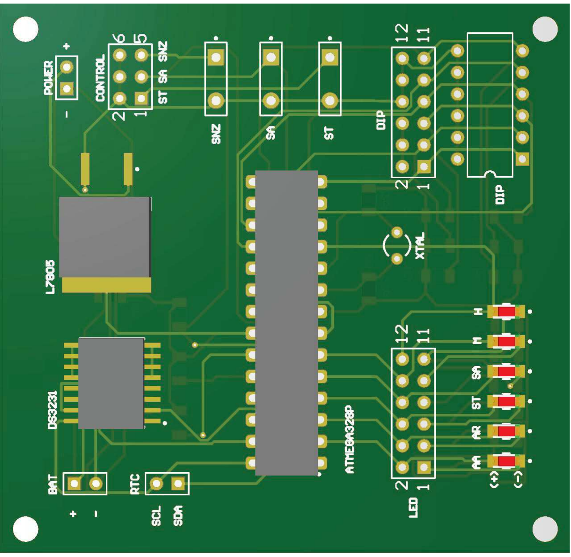
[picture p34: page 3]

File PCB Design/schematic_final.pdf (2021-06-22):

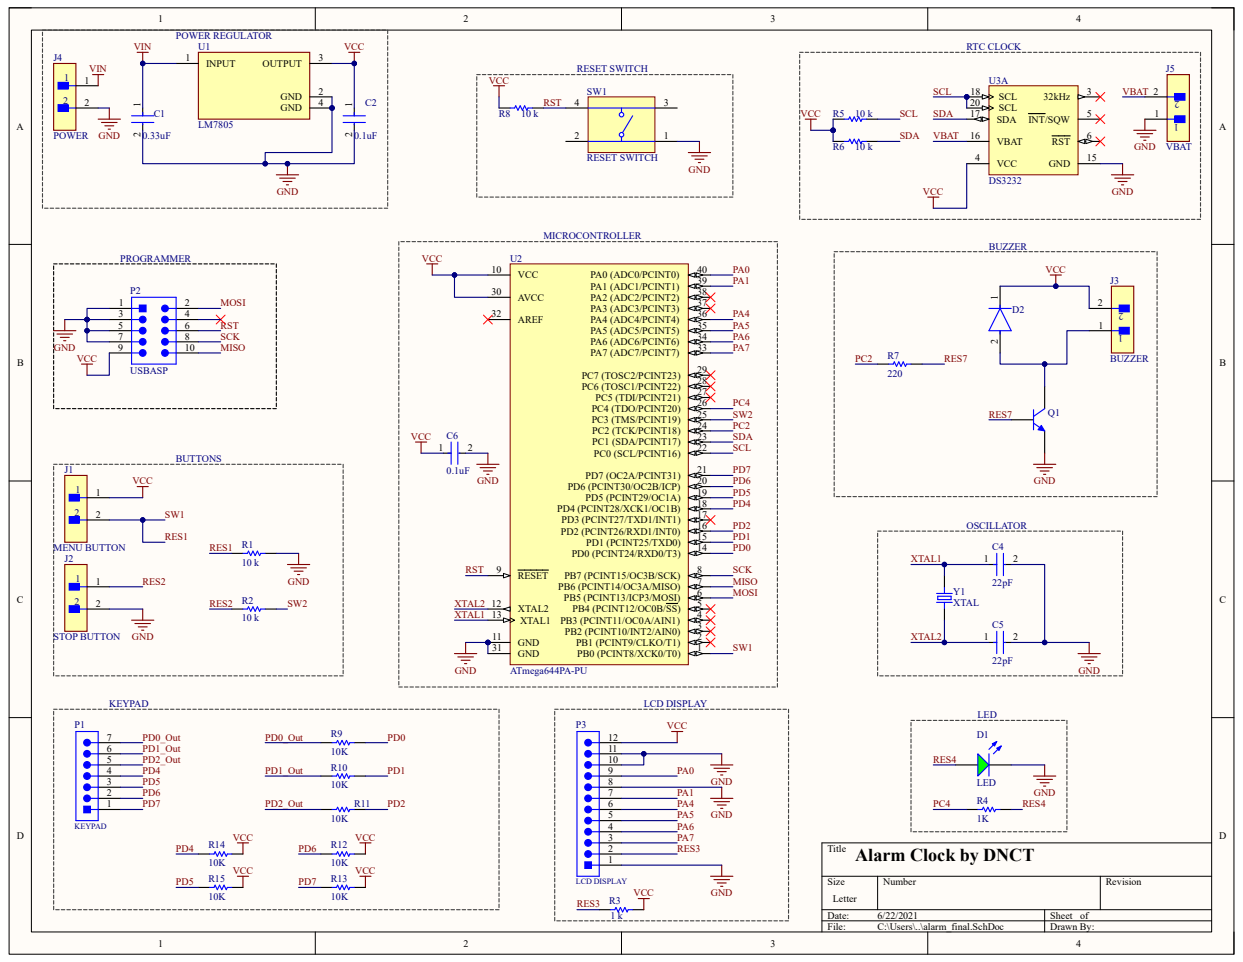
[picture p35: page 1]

Title
Alarm Clock by DNCT

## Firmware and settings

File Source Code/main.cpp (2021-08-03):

/*
 * Alarm_Clock.cpp
 *
 * Created: 6/8/2021 1:40:08 AM
 * Author : Chathuni
 */ 

#ifndef F_CPU
#define F_CPU 16000000UL
#endif

#include <avr/io.h>
#include <avr/interrupt.h>
#include <stdio.h>
#include <util/delay.h>

#include "lcd.h"
#include "keypad.h"
#include "alarm_timing.h"

#define SDA PINC1
#define SCL PINC0
#define Ring PINC4	

// initializing global variables
DS3231 RTC(SDA,SCL);

Alarm alarm1,alarm2,alarm3,alarm4;
Alarm alarm_list[4] = {alarm1,alarm2,alarm3,alarm4};

// function prototypes
void Alarm_Options(Alarm *alarm_list,int i);
void Alarm_Menu();
void Set_Time_Menu();
void Menu();

volatile uint8_t count;
volatile int prev_hour,prev_min;

int main(void)
{
    RTC.begin();
	LCD_Init();
	
	DDRC |= (1 << Ring);
	PORTC |= 1 << PIN_STOP_ALARM;
	
	int menu;
	prev_hour = 61;
	prev_min = 61;
	
	// initializing interrupt for ringing the alarm
	TCNT1 = 57724;
	count = 0;
	TCCR1A = 0x00;
	TCCR1B |= (1<<CS12) | (1<<CS10);	 // PRESCALER 1024
	TIMSK1 = (1<<TOIE1);
	
	sei(); 
	
	while (1) 
    {
		Time t = RTC.getTime();			// get the current time as a Time object
		
		LCD_Home(RTC,prev_hour,prev_min);

		// variables to avoid clearing and writing when the time has not changed
		prev_hour = t.hour;
		prev_min = t.min;	
	
		menu = menu_read();				// check if menu button is pressed
		
		if (menu == 1)
		{
			Menu();						// execute menu function
			prev_hour = 61;
			prev_min = 61;						
		}
		_delay_ms(100);
    }
}

// if overflow interrupt occurs check for alarm
ISR (TIMER1_OVF_vect)
{	
	TCNT1 = 57724;
	Time t = RTC.getTime();			// get the current time as a Time object
	
/*	PORTC |=  (1<<Ring);*/
	_delay_ms(100);	
/*	PORTC &= ~(1<<Ring);*/
	
	// check if any alarm time has reached
	for (int i = 0; i < 4; i++)		// iterating through each alarm
	{
		if ((alarm_list[i].active == 1) && (t.hour == alarm_list[i].hour) && (t.min == alarm_list[i].minute))	// check for ring time of an active alarm
		{
			PORTC |=  (1<<Ring);// debug
			alarm_list[i].ring();
			PORTC &= ~(1<<Ring);
			prev_hour = 61;
			prev_min = 61;
			break;
		}
	}

}

// Main menu function
void Menu()
{
	LCD_Menu();
	
	int input = Keypad_read();
	
	switch (input)
	{
		case 1:		// Set Time and Date
			Set_Time_Menu();
			break;
		case 2:		// Set Alarm
			Alarm_Menu();
			break;
		case 3:		// Reset the clock
			reset_time(RTC);
			timing_delete_alarms(alarm_list);
			break;
		case 10:		// Back
			return;
		default:	// None of the above (invalid input)
			LCD_Invalidinput();
			_delay_ms(1000);
			Menu();	// Call Menu function recursively
	}
	return;
}

// Set Time Menu function
void Set_Time_Menu()
{
	LCD_SetTimeMenu();
	
	int input = Keypad_read();
	
	switch (input)
	{
		case 1:		// Set Time
			timing_set_time(RTC);
			break;
		case 2:		// Set Date
			timing_set_date(RTC);
			break;
		case 10:		// Back (base case of the recursive function)
			Menu();
			return;
		default:	// invalid input
			LCD_Invalidinput();
			_delay_ms(1000);
			break;
	}
	
	Set_Time_Menu();	// navigate back to Set Time Menu after each setting except Back
	return;
}

void Alarm_Menu()
{	 
	LCD_AlarmList1(alarm_list);
	
	while (true)
	{
		int input = Keypad_read();
		
		if (input == 1 || input == 2 || input == 3 || input == 4 || input == 5 || input == 6 ) // if the user has selected an alarm
		{
			Alarm_Options(alarm_list,input-1);
			break;
		}
		
		else if (input == 20)
		{
			LCD_AlarmList2(alarm_list);
		}
		else if (input == 10)	// Back
		{
			Menu();
			break;
		}
		else	// invalid input
		{
			LCD_Invalidinput();
			_delay_ms(1000);
		}
	} 
	
	return;
}

void Alarm_Options(Alarm *alarm_list,int i)
{
	LCD_AlarmMenu();
	
	int input = Keypad_read();
	
	switch (input)
	{
		case 1:	 // Set
			timing_set_alarm(alarm_list,i);
			break;
		case 2:	 // Delete
			alarm_list[i].del();;
			break;
		case 3:	 // Set Tone
			alarm_list[i].set_tone();
			break;
		case 10:	 // Back
			Alarm_Menu();
			return;
		default: // invalid input
			LCD_Invalidinput();
			_delay_ms(1000);
			break;
	}
	
	Alarm_Options(alarm_list,i);
	return;
}

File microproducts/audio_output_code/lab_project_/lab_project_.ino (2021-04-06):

#include "notes.h"
#include "tones.h"

// change this to make the song slower or faster
int speed_adjust = 100;
int button_state = 0;
int length_notes_=0;


void setup() {
  // put your setup code here, to run once:
  pinMode(11, OUTPUT);
  pinMode(5, INPUT);
  pinMode(6, INPUT);
  pinMode(7, INPUT);
  pinMode(8,INPUT); 
  
}

void playTone(int length_notes, int playing_melody[],int pin){
  int complete_duration = (60000 * 4)/ speed_adjust; // complete duration of the tone
  int given_note_time = 0, duration = 0;
  for (int Note = 0; Note < length_notes * 2; Note = Note + 2){
    given_note_time= playing_melody[Note+1];
    if (given_note_time >0){
      duration=complete_duration/given_note_time;
    } else if (given_note_time <0){
      duration=complete_duration/abs(given_note_time);
      duration *= 1.5;
      
    }
    
    tone(11, playing_melody[Note], duration * 0.9);
    delay(duration);
    noTone(11);
    if (digitalRead(pin)==(LOW)){
      break;
      
    }
  }
      
  }

void loop(){// play a selected tone 
  //int duration = (60000 * 4) / speed_adjust; // complete duration of the tone
  if (digitalRead(6)==  HIGH)// reading the 6 th pin value
  {
    while ((digitalRead(6)==HIGH) == 1)
    {
      length_notes_=Greensleves_notes;
      //int playing_melody_[]=Greensleves;
      int pin1=6;
      
      playTone(Greensleves_notes,Greensleves,pin1);
    }
  }
    
      
  
  else if (digitalRead(7)==HIGH)// reading the 7 th pin value
  {
    while ((digitalRead(7)==HIGH)==1){
      //length_notes_=harry_potter_notes;
      //playing_melody_= harry_potter_melody;
      int pin2=7;
      playTone(harry_potter_notes,harry_potter_melody,pin2);
    }
  }
  else if (digitalRead(8)==HIGH)// reading the 8 th pin value
  {
    while ((digitalRead(8)==HIGH) == 1){
      //length_notes_=game_of_throns_notes;
      //playing_melody_=game_of_throns_melody;
      int pin3=8;
      playTone(game_of_throns_notes,game_of_throns_melody,pin3);
    }
  }
  else if (digitalRead(5)==HIGH)// reading the 8 th pin value
  {
    while ((digitalRead(5)==HIGH) == 1){
      //length_notes_=Star_Wars_theme;
      //playing_melody_=Star_Wars_theme_melody;
      int pin4=5;
      playTone(Star_Wars_theme_notes,Star_Wars_theme_melody,pin4);
    }
  }
  else 
  {
    noTone(11);
  }
      
   
}

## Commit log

2021-03-28 initialize stage 1 arduino source code
2021-03-31 display hello world
    [menu_display_circuit.brd]
2021-03-31 printing any input through serial input
2021-03-31 1-commti for arduino code
2021-04-01 Adding another LED to code
2021-04-04 Lighting LED at alarm time
2021-04-04 added 3 buttons to change displayed number
    [menu_display_circuit.brd]
2021-04-26 added delay for switch bounce and added proteus file
2021-04-26 first display using atmega and avr c++
    [menu_display_circuit.brd]
2021-05-02 Added 3 buttons
2021-05-02 increase decrease functions for buttons
2021-05-07 added schematics and pcb layout - altium
    [alarm_clock.PcbDoc, alarm_clock.PcbLib, alarm_clock.PrjPcb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]
2021-05-08 added the solidowrks enclosure
    [Part35^alarm_clock.SLDPRT]
2021-05-20 pcb added
    [PCB1.PcbDoc, PCB_Project.PrjPcb, Sheet1.SchDoc]
2021-05-20 change the mounting hole
    [PCB1.PcbDoc]
2021-05-20 solid work file add
    [PCB1.PcbDoc, PCB1.SLDASM, PCB1.step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]
2021-05-20 change led directions to front side and make step file
    [PCB2.step]
2021-05-21 create mounting boss
2021-05-22 add upperside mounting boss
    [PCB2.SLDASM]
2021-05-27 change powerline width to 25mm
    [PCB1.PcbDoc]
2021-05-31 make key pad wire hole
    [PCB2.SLDASM]
2021-05-31 led lightinng part take out side of function
2021-05-31 Understandable code. Updated PCB. Add Snaphooks
    [Bot.SLDPRT, Top.SLDPRT, alarm_clock.PcbDoc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]
2021-05-31 make hole for switch
    [Assem1.SLDASM]
2021-05-31 make switch hole
    [PCB2.SLDASM]
2021-06-01 Upload enclosure files
2021-06-01 Upload PCB Design Files
2021-06-10 fixed switch
2021-06-10 Final Code
    All the functions working
    Bugs fixed
    [lcd.h, main.cpp]
2021-06-11 Added interrupts for Alarm ringing
    Enabled interrupt driven alarm ringing to ring alarm while in the menu
2021-06-12 Create PCB Design Folder
    Create a folder for the PCB Design
2021-06-12 added schematic
2021-06-22 deleted schematic
2021-06-22 added pcb layout
2021-08-03 bugs fixed
    Added a scrolling option to the alarm menu
    Bug fixed in alarm detecting using interrupts - timer changed to timer1 of 16 bits
    [lcd.h, main.cpp]
